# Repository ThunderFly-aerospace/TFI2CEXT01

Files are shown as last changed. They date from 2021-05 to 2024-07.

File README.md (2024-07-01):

# TFI2CEXT01A - I²C bus extender

I²C bus extension module. This module allows an extension of the usable total length of the I2C bus on the UAV. Most I2C bus instances benefit from having TFI2CEXT positioned midway between master and slave, where its signal amplification is most effective in both directions.

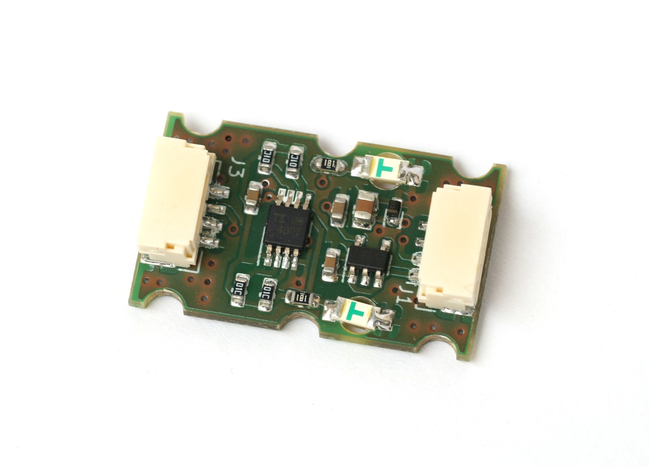
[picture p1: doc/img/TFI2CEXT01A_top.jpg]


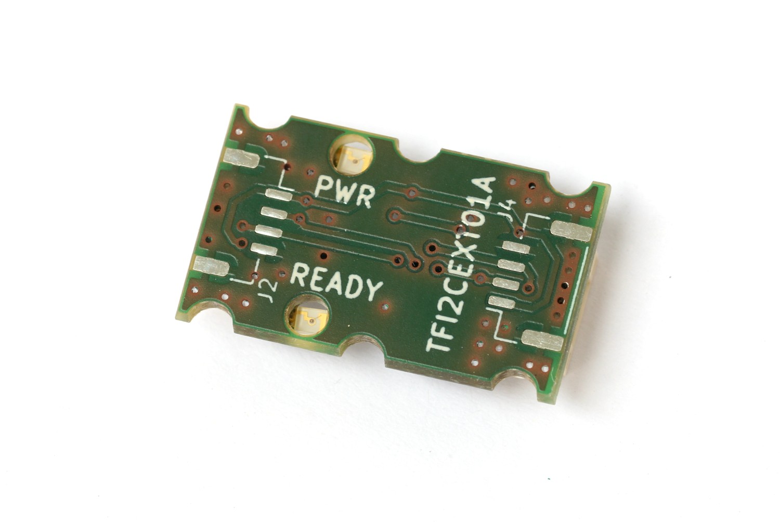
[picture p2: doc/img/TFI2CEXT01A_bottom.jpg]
Bottom view on I2C bus extender


In practice, I2C devices vary in driving capability, and I2C signals are often affected by capacitive load or unwanted signal coupling. TFI2CEXT can effectively isolate bus segments, ensuring devices only see the segment's wiring load up to the TFI2CEXT. Thus, placing TFI2CEXT closer to the "problematic" I²C device is optimal.

## Where to get it?

ThunderFly TFI2CEXT01A counter is commercially available from [ThunderFly s.r.o.](https://www.thunderfly.cz/), write an email to info@thunderfly.cz. Or shop it on [Tindie.](https://www.tindie.com/products/thunderfly/tfi2cext01-pixawk-i2c-bus-extender/)

## Parameters

| Parameter | Value | Description |
|---|---|---|
| Data rate | Up to 400 kHz | Limited by used [TCA4307 IC](https://www.ti.com/product/TCA4307) |
| I2C Connector | 2x 4-pin JST-GH | Connected in parallel |
| Operating and storage temperature | -20 - +40°C | Limited by case material |
| Operational input voltage | 3.6 - 5.4V |  |
| Mass | ~2 g | PCB |
| Dimensions | 15x25x6(10.5) | One-sided connectors (With connector on both sides) |
| Weather resistance | IP00 |  |

## Features

  * Input Power status LED indicator
  * Optionally possible to solder pass-through I²C connectors to allow a daisy chain of different sensors
  * Ability to isolate I2C bus segments by disconnecting frozen devices
  * Capability to handle differently the Master and a slave bus sides
  * The extender can perform a device reset in case it seems frozen or unresponsive.
  * READY signal indication of the correct connection of both I2C bus sides.

The two I²C Pixhawk connectors on the bottom and top are connected directly. This feature allows easy nesting with other I²C devices onto existing functional bus cabling.

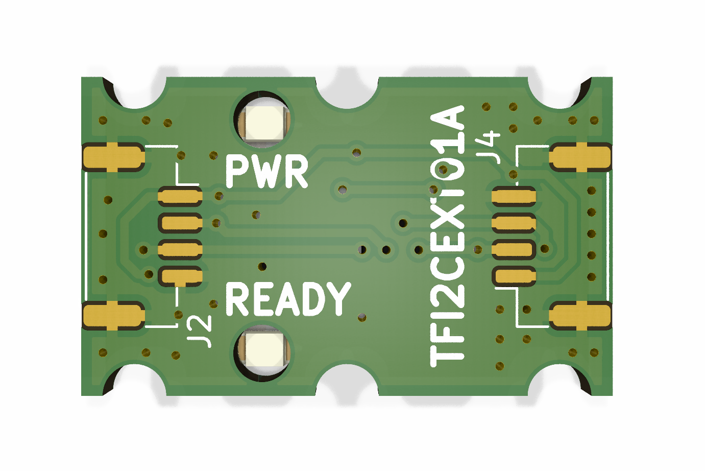
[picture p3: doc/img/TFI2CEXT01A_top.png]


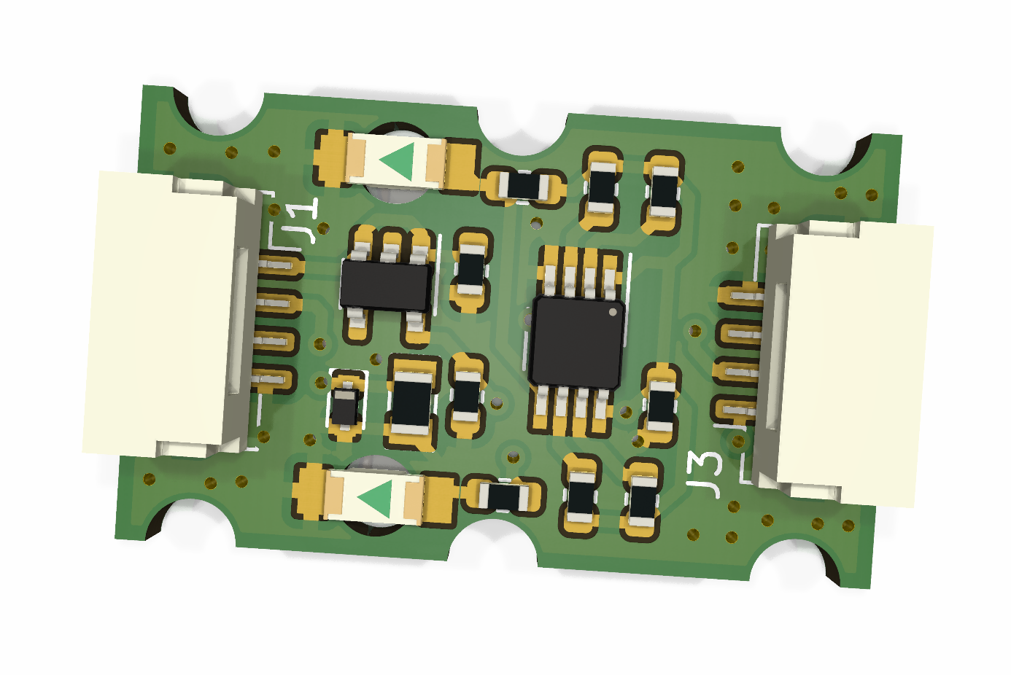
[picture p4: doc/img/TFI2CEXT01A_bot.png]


### Device Reset

The TCA4307 has a stuck bus recovery feature. It disconnects the slave side if SDAOUT or SCLOUT is low for about 40 ms, then generates up to 16 pulses on SCLOUT to reset the bus. The slave side reconnects only after the issue is resolved.

### PCB dimensions

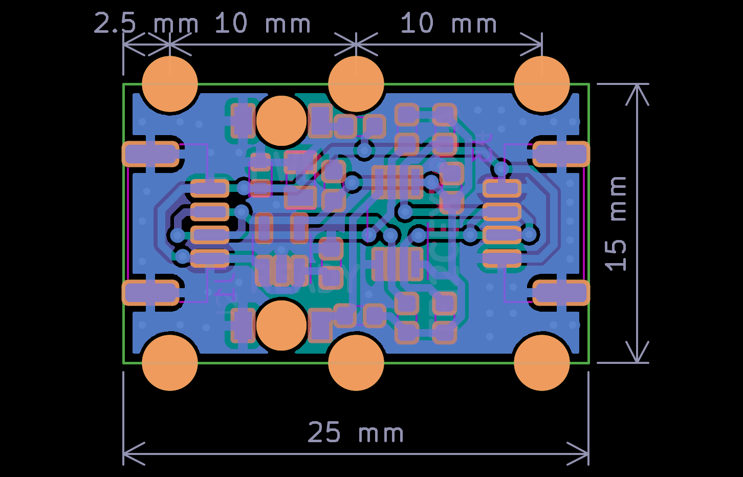
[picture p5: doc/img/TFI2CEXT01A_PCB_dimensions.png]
PCB dimensions


The PCB is designed to be mounted in the slit and fixed by screws on the sides. The supposed screw diameter is metric 3mm e.g. DIN 912 M3 Hexagon socket Head Cap Screws.

## Documentation

The additional documentation is available on the [ThunderFly docs website](https://docs.thunderfly.cz/avionics/TFI2CEXT/). 

### Connection 

Due to the device reset capability of TFI2CEXT01 special attention should be dedicated to the proper connection of the module to the UAV. The connector closer to the LEDS should be connected to the Master (e.g. autopilot). The opposite connector at the far side from LEDs should be connected to I²C slaves, e.g. sensors.

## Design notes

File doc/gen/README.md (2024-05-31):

# PCB

Board size: 25.0x15.0 mm (0.98x0.59 inches)

- This is the size of the rectangle that contains the board
- Thickness: 1.6 mm (63 mils)
- Material: FR4
- Finish: None
- Layers: 2
- Copper thickness: 35 µm

Solder mask: TOP / BOTTOM

- Color: Green

Silk screen: TOP / BOTTOM

- Color: White

Stackup:

| Name | Type | Color | Thickness | Material | Epsilon_r | Loss tangent |
|---|---|---|---|---|---|---|
| F.SilkS | Top Silk Screen | | | | | |
| F.Paste | Top Solder Paste | | | | | |
| F.Mask | Top Solder Mask | Green | 10 | | | |
| F.Cu | copper | | 35 | | | |
| dielectric 1 | core | | 1510 | FR4 | 4.5 | 0.020 |
| B.Cu | copper | | 35 | | | |
| B.Mask | Bottom Solder Mask | Green | 10 | | | |
| B.Paste | Bottom Solder Paste  | | | | | |
| B.SilkS | Bottom Silk Screen | | | | | |

# Important sizes

Clearance: 0.2 mm (8 mils)

Track width: 0.25 mm (10 mils)

- By design rules: 0.2 mm (8 mils)

Drill: 0.5 mm (20 mils)

- Vias: 0.5 mm (20 mils) [Design: 0.4 mm (16 mils)]
- Pads: 3.0 mm (118 mils)
- The above values are real drill sizes, they add 0.1 mm (4 mils) to plated holes (PTH)

Via: 0.8/0.4 mm (31/16 mils)

- By design rules: 0.4/0.3 mm (16/12 mils)
- Micro via: yes [0.2/0.1 mm (8/4 mils)]
- Buried/blind via: yes
- Total: 47 (thru: 47 buried/blind: 0 micro: 0)

Outer Annular Ring: 0.15 mm (6 mils)

- By design rules: N/A mm (N/A mils)

Eurocircuits class: 4B
- Using min drill 0.5 mm for an OAR of 0.15 mm

# General stats

Components count: (SMD/THT)

- Top: 2/6 (SMD + THT)
- Bottom: 17/0 (SMD)

Defined tracks:

Used tracks:

- 0.25 mm (10 mils) (2) defined: no
- 0.3 mm (12 mils) (1) defined: no
- 0.4 mm (16 mils) (144) defined: no

Defined vias:

Used vias:

- 0.8/0.4 mm (31/16 mils) (Count: 47, Aspect: 2.0 A) defined: no

Holes (excluding vias):

- 3.0 mm (118 mils) (6)

Oval holes:

Drill tools (including vias and computing adjusts and rounding):

- 0.5 mm (20 mils) (47)
- 3.0 mm (118 mils) (6)

Solder paste stats:

Using a paste with 87.75 % alloy, that has an specific gravity for the alloy of 7.4 g/cm³
and 1.0 g/cm³ for the flux. This paste has an specific gravity of  4.15 g/cm³.

The stencil thickness is  0.12 mm.

| Side | Pads with paste | Area [mm²] | Paste [g] |
|---|---|---|---|
| Top | 12 | 18.56 | 0.09 |
| Bottom | 51 | 51.67 | 0.26 |
| Total  | 63 | 70.22 | 0.35 |

Note: this is just an approximation to the theoretical value. Margins of the solder mask and waste aren't computed.

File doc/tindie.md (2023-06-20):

## What is TFI2CEXT? 

TFI2CEXT01 is a device or module, that contains an I2C bus buffer, the electronic component that enhances the signal on an I2C bus. The buffer creates a signal that is less prone to interference or large capacity of wires which is a common issue among usual I2C devices. Thanks to this feature, it is possible, for example, to elongate the I2C bus or connect more devices to one I2C bus. 

TFI2CEXT is designed directly for use in drone avionics. For this purpose, for example, it features a JST-GH connector with a pinout corresponding to the Pixhawk standard on both input and output.

## What makes TFI2CEXT special? 

ThunderFly I2CEXT device is unique in that it can be connected directly (without major changes) to the infrastructure of drones based on the Pixhawk standard.

## What are TFI2CEXT main features?
  
  * Input Power status LED indicator
  * Optional possibility of soldering pass-through I²C connectors to allow a daisy chain topology
  * Ability to isolate I2C bus segments by disconnecting frozen devices (Frozen devices are automatically attempted to reset)
  * Capability to handle a master and a slave bus sides differently
  * The extender is capable to perform a device reset if it seems to be frozen
  * READY signal indication of the correct connection of both I2C bus sides

The main reason for developing TFI2CEXT was that we repeatedly experienced a state when an I2C bus on drones was not reliable enough to be used safely. After developing our device the situation improved significantly and the problems with communication on the I2C bus disappeared.

## How TFI2CEXT could be used?

Using the I2C extender is very simple - it works by plugging into the bus, preferably into the middle of the bus wire's longest section. The PCB can be fitted with JST-GH connectors from both sides, the connectors are connected in parallel. This allows the TFI2CEXT PCB to act as a small I2C hub. There are 2 input connectors (before the I2C buffer) and 2 connectors enhanced by the I2C buffer.

The module contains 2 LED diodes. One indicates the presence of a power supply and should be lit all the time the power supply is present. The second - READY LED - lights up only if both sides of the bus are connected, the module is functional and ready to enhance the I2C bus transmissions.

### Compatibility

The bus buffer does not need any software configuration. Thanks to this, it can be used with any Pixhawk autopilot compatible firmware like [PX4](https://px4.io/) or [Ardupilot](https://ardupilot.org/) additionally the usage is not limited to UAVs only.

## What package includes

- TFI2CEXT01A
- Two spare JST-GH PCB connectors (only two connectors are soldered on PCB by default)

## Accessories

### I2C cables
I2C cables for connecting to the autopilot are not included in the package. You will need to purchase the cables separately from our [tindie catalog](https://www.tindie.com/stores/thunderfly/). We offer high-quality cables that are compatible with the [Pixhawk standard](https://raw.githubusercontent.com/pixhawk/Pixhawk-Standards/master/DS-009%20Pixhawk%20Connector%20Standard.pdf) and with a [ThunderFly color](https://docs.px4.io/main/en/assembly/cable_wiring.html#i2c-cables) scheme for easy signal identification. Our cables are specifically designed with improved resistance to electromagnetic interference and made with silicone insulation that makes them highly flexible.

  * Length 15 cm - [TFCAB15I2C01](https://www.tindie.com/products/thunderfly/tfcabxxi2c01-i2c-cable-for-pixhawk-drones/)
  * Length 30 cm - [TFCAB30I2C01](https://www.tindie.com/products/thunderfly/tfcabxxi2c01-i2c-cable-for-pixhawk-drones/)
  * Length 45 cm - [TFCAB45I2C01](https://www.tindie.com/products/thunderfly/tfcabxxi2c01-i2c-cable-for-pixhawk-drones/)

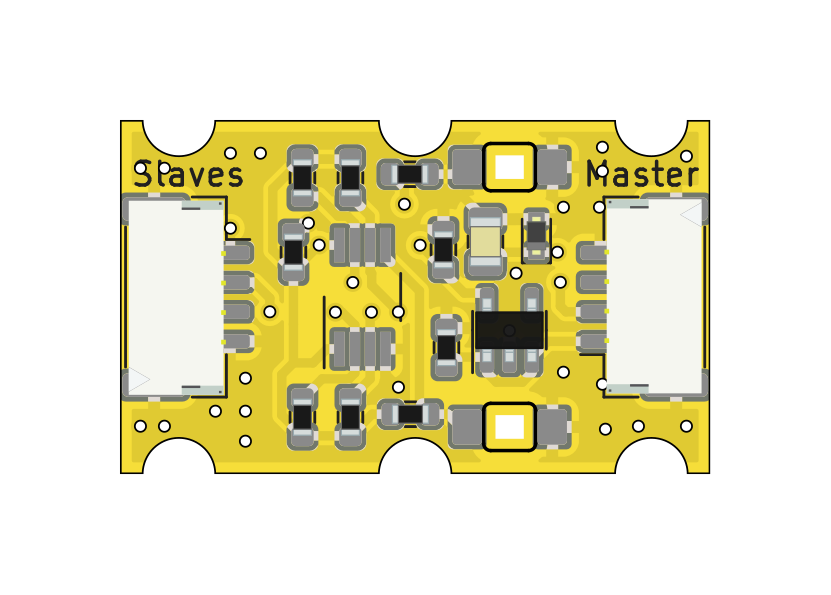
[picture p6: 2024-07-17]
doc/gen/img/TFI2CEXT01-bottom.png

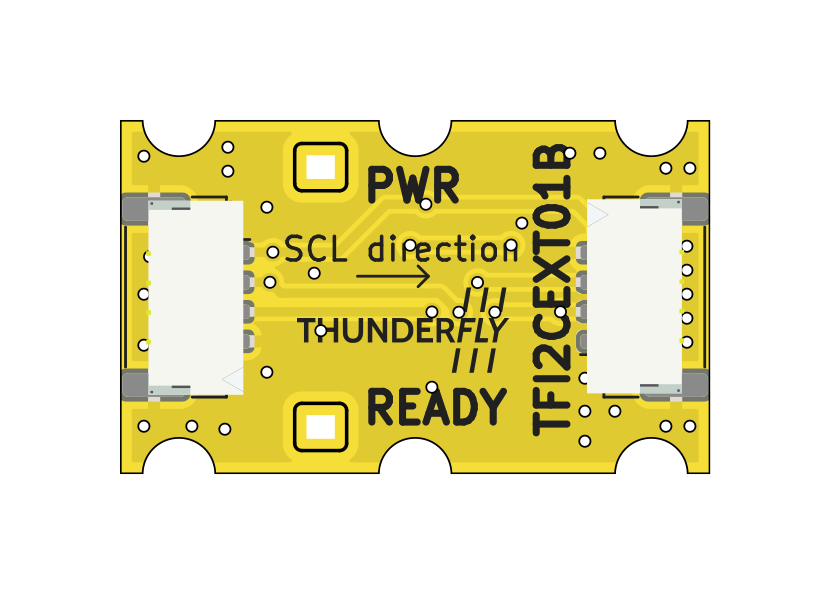
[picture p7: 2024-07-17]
doc/gen/img/TFI2CEXT01-top.png

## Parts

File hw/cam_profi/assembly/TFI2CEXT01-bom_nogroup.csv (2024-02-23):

Component | Description | Part | References | Value | Footprint | Quantity Per PCB | Datasheet | ust_id
1 | Unpolarized capacitor | C | C2C4 | 100nF | R_0603_1608Metric | 2 | ~ | 5c70984812875079b91f8bf2
2 | Unpolarized capacitor | C | C3 | 1uF | R_0603_1608Metric | 1 | ~ | 5c70984812875079b91f8bc2
3 | Unpolarized capacitor | C | C1 | 10uF | C_0805_2012Metric | 1 | ~ | 5c70984812875079b91f8bbd
4 |  | D_ZENER | D2 | BZX585-B5V6.115 | D_SOD-523 | 1 |  | 60879d38128750769ee58e48
5 | Light emitting diode | LED | D1 | LED GREEN | LED_1206_mill | 1 | ~ | 5c70984412875079b91f8895
6 | Light emitting diode | LED | D3 | LED RED | LED_1206_mill | 1 | ~ | 5c70984412875079b91f8896
7 | 1x05 2.54 mm pitch header | SM04B-GHS-TB | J1J2J3J4 | SM04B-GHS-TB | JST_GH_SM04B-GHS-TB_1x04-1MP_P1.25mm_Horizontal | 4 |  | 5c86273d1287500b4e0280be
8 |  | HOLE | M1M2M3M4M5M6 | HOLE | dira_3mm | 6
9 | Resistor | R | R1 | 130R | R_0603_1608Metric | 1 | ~ | 5cd08b17128750448e4542b1
10 | Resistor | R | R4 | 287R | R_0603_1608Metric | 1 | ~ | 651a975c462c6d9e7205504d
11 | Resistor | R | R2R3R5R6 | 10k | R_0603_1608Metric | 4 | ~ | 5c70984512875079b91f8962
12 | 300mA Low-dropout Voltage Regulator, Vout 3.3V, Vin up to 5.5V, SOT-23 | MIC5504-3.3YM5 | U1 | MIC5504-3.3YM5 | SOT-23-5 | 1 | http://ww1.microchip.com/downloads/en/DeviceDoc/MIC550X.pdf | 5c7255e81287500b4e112ea2
13 |  | TCA4307 | U2 | TCA4307 | VSSOP-8_3.0x3.0mm_P0.65mm | 1 | https://www.ti.com/lit/ds/symlink/tca4307.pdf?ts=1617607418171 | 6087a3f3128750769ee58f03

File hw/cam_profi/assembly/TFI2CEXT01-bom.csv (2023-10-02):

Row | Description | Part | References | Value | Footprint | Quantity Per PCB | Status | Datasheet | UST_id
1 | Unpolarized capacitor | C | C2 C4 | 100nF | R_0603_1608Metric | 2 |  |  | 5c70984812875079b91f8bf2
2 | Unpolarized capacitor | C | C3 | 1uF | R_0603_1608Metric | 1 |  |  | 5c70984812875079b91f8bc2
3 | Unpolarized capacitor | C | C1 | 10uF | C_0805_2012Metric | 1 |  |  | 5c70984812875079b91f8bbd
4 |  | D_ZENER | D2 | BZX585-B5V6.115 | D_SOD-523 | 1 |  |  | 60879d38128750769ee58e48
5 | Light emitting diode | LED | D1 | LED GREEN | LED_1206_mill | 1 |  |  | 5c70984412875079b91f8895
6 | Light emitting diode | LED | D3 | LED RED | LED_1206_mill | 1 |  |  | 5c70984412875079b91f8896
7 | 1x05 2.54 mm pitch header | SM04B-GHS-TB | J1 J2 J3 J4 | SM04B-GHS-TB | JST_GH_SM04B-GHS-TB_1x04-1MP_P1.25mm_Horizontal | 4 |  |  | 5c86273d1287500b4e0280be
8 |  | HOLE | M1 M2 M3 M4 M5 M6 | HOLE | dira_3mm | 6
9 | Resistor | R | R1 | 130R | R_0603_1608Metric | 1 |  |  | 5cd08b17128750448e4542b1
10 | Resistor | R | R4 | 287R | R_0603_1608Metric | 1 |  |  | 651a975c462c6d9e7205504d
11 | Resistor | R | R2 R3 R5 R6 | 10k | R_0603_1608Metric | 4 |  |  | 5c70984512875079b91f8962
12 | 300mA Low-dropout Voltage Regulator, Vout 3.3V, Vin up to 5.5V, SOT-23 | MIC5504-3.3YM5 | U1 | MIC5504-3.3YM5 | SOT-23-5 | 1 |  | http://ww1.microchip.com/downloads/en/DeviceDoc/MIC550X.pdf | 5c7255e81287500b4e112ea2
13 |  | TCA4307 | U2 | TCA4307 | VSSOP-8_3.0x3.0mm_P0.65mm | 1 |  | https://www.ti.com/lit/ds/symlink/tca4307.pdf?ts=1617607418171 | 6087a3f3128750769ee58f03
Project info:
Schematic: | TFI2CEXT01
Variant: | default
Revision:
Date: | 2021-04-05
KiCad Version: | 7.0.7-7.0.7~ubuntu23.04.1
Statistics:
Component Groups: | 13
Component Count: | 25
Fitted Components: | 25
Number of PCBs: | 1
Total Components: | 25

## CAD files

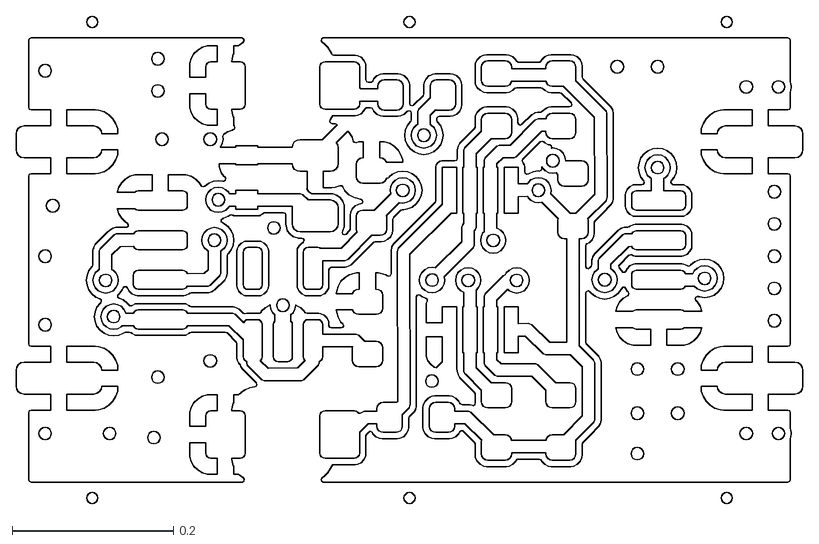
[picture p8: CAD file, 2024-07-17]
doc/gen/dxf/TFI2CEXT01-B_Cu.dxf
0.976 x 0.604

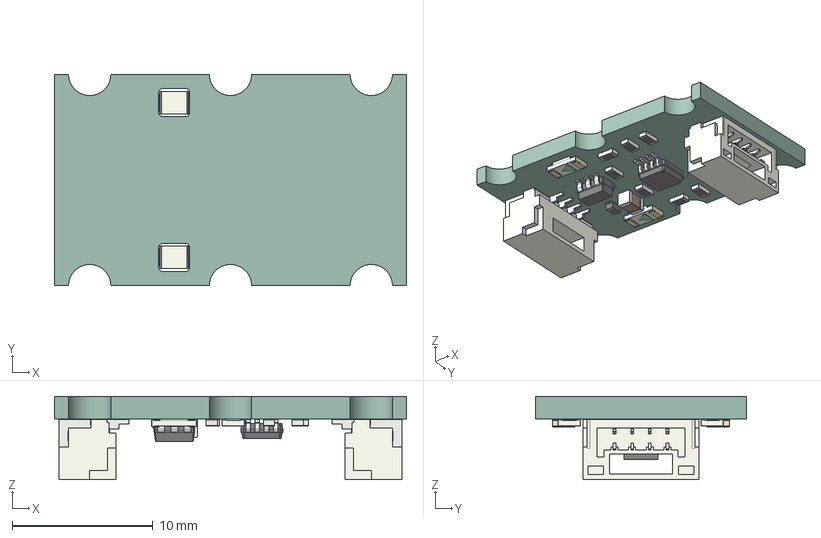
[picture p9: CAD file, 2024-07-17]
doc/gen/TFI2CEXT01.step
25.0 x 15.0 x 5.89 mm
R_0603_1608Metric x 9
VSSOP_8_30x30mm_P065mm
LED_1206_3216Metric x 2
D_SOD_523
JST_SM04B_GHS_TB x 2
SOT_23_5
C_0805_2012Metric
kibot_1q7gwn4h_PCB

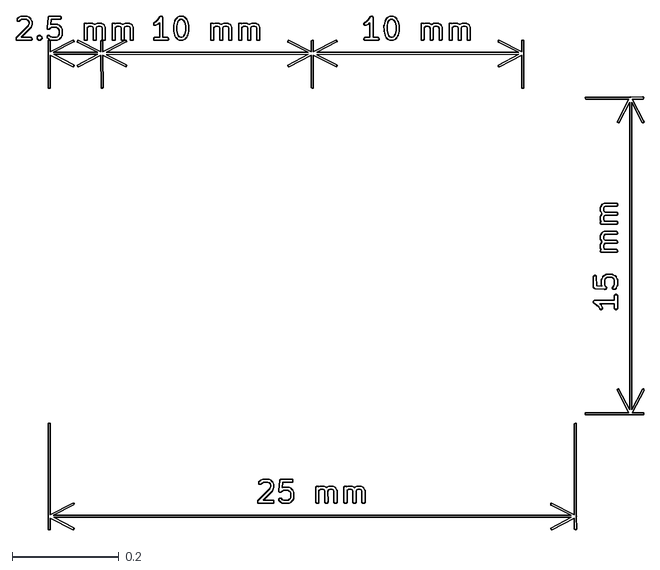
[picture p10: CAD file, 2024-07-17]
doc/gen/dxf/TFI2CEXT01-User_Drawings.dxf
1.17 x 0.961

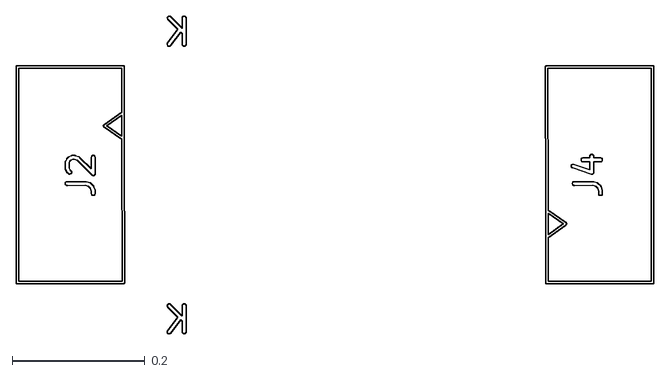
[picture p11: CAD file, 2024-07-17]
doc/gen/dxf/TFI2CEXT01-F_Fab.dxf
0.961 x 0.478

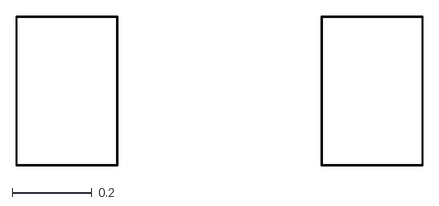
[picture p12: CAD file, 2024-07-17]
doc/gen/dxf/TFI2CEXT01-F_Courtyard.dxf
1.02 x 0.374

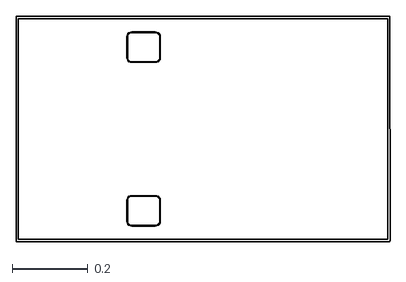
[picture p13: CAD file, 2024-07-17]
doc/gen/dxf/TFI2CEXT01-Edge_Cuts.dxf
0.99 x 0.596

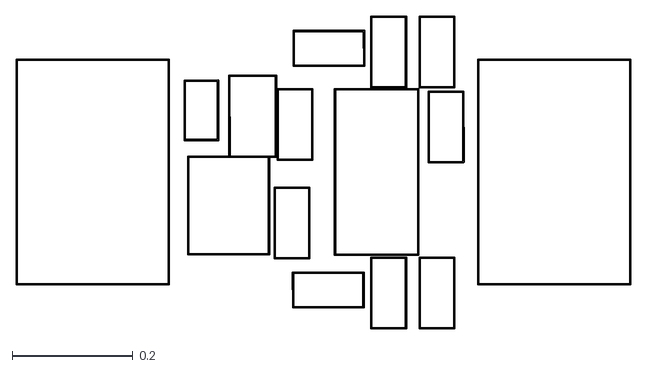
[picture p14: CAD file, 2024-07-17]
doc/gen/dxf/TFI2CEXT01-B_Courtyard.dxf
1.02 x 0.518

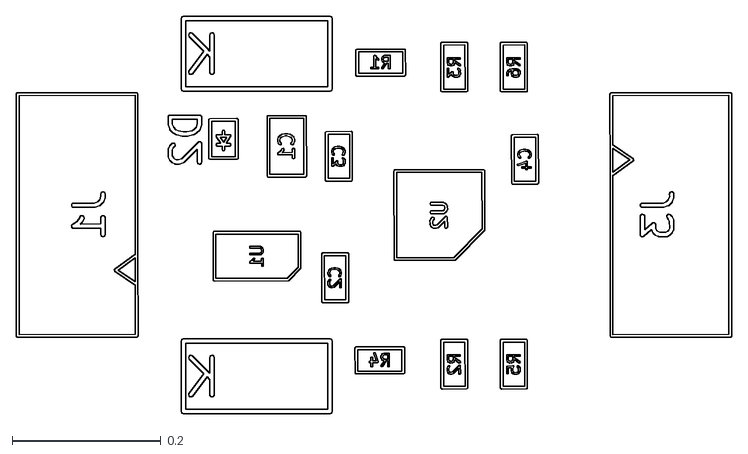
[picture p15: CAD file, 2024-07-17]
doc/gen/dxf/TFI2CEXT01-B_Fab.dxf
0.961 x 0.533

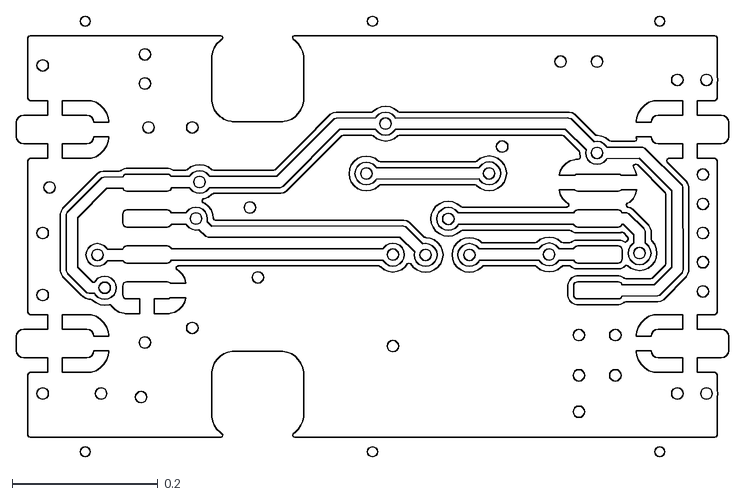
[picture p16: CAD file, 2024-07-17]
doc/gen/dxf/TFI2CEXT01-F_Cu.dxf
0.976 x 0.604

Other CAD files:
doc/gen/dxf/TFI2CEXT01-Margin.dxf
doc/gen/dxf/TFI2CEXT01-B_Mask.dxf
doc/gen/dxf/TFI2CEXT01-B_Paste.dxf
doc/gen/dxf/TFI2CEXT01-B_Silkscreen.dxf
doc/gen/dxf/TFI2CEXT01-F_Mask.dxf
doc/gen/dxf/TFI2CEXT01-F_Paste.dxf
doc/gen/dxf/TFI2CEXT01-F_Silkscreen.dxf

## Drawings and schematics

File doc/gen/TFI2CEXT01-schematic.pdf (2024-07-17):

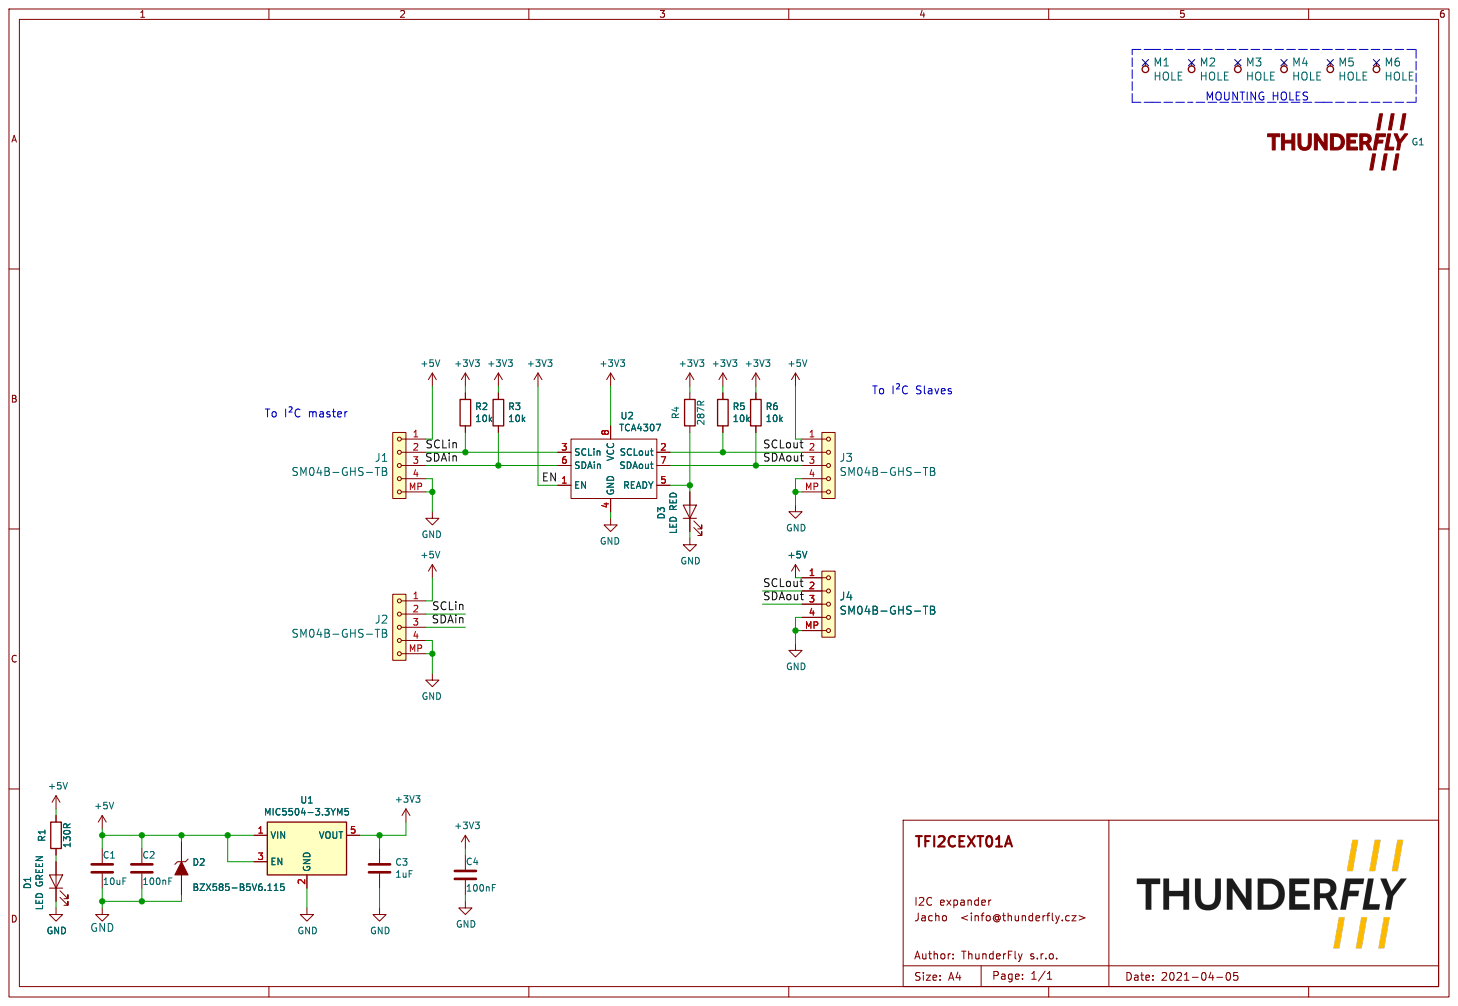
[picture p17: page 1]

4 READY 5 SDAin 6 SDAout VCC 7

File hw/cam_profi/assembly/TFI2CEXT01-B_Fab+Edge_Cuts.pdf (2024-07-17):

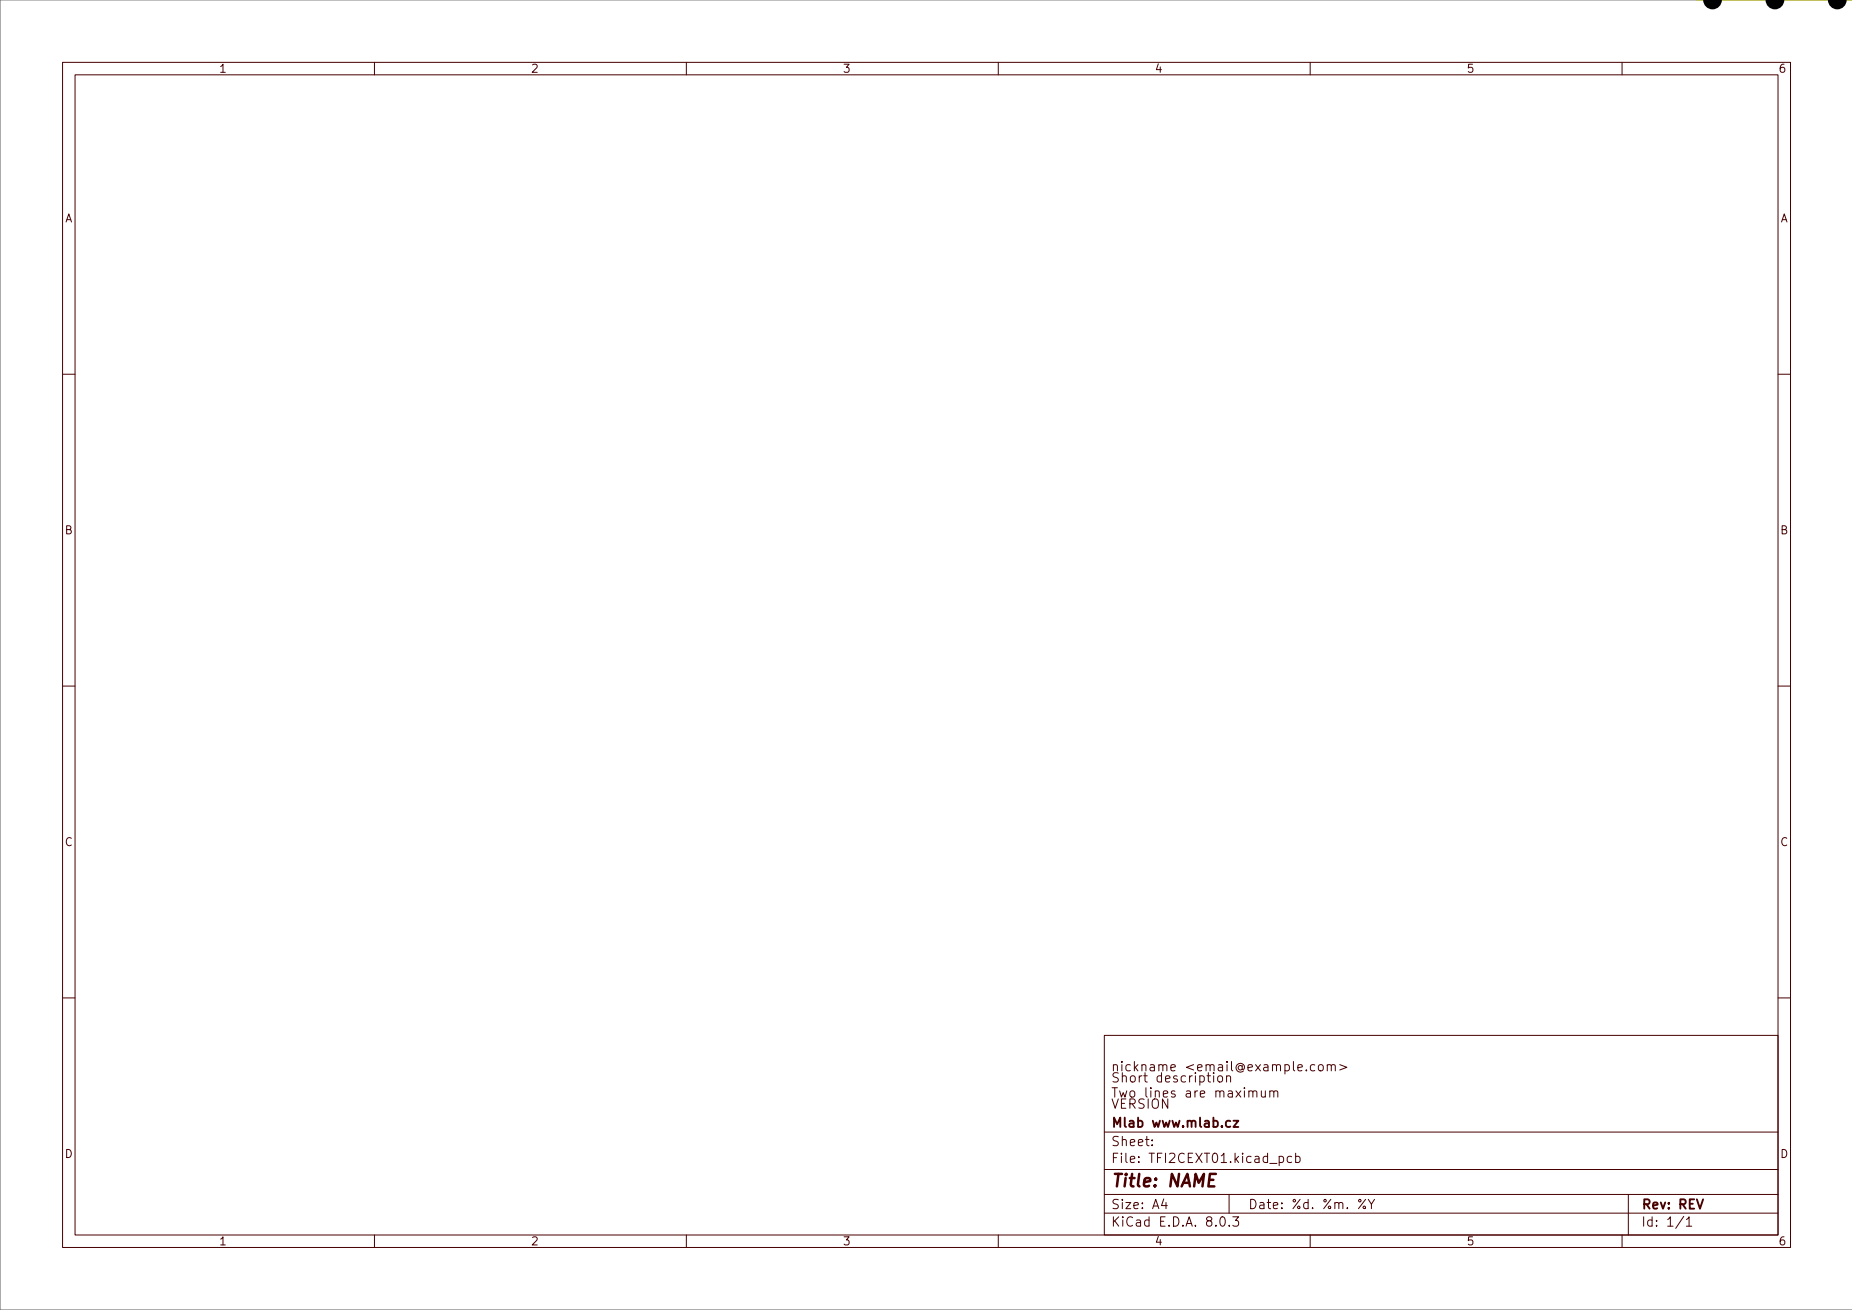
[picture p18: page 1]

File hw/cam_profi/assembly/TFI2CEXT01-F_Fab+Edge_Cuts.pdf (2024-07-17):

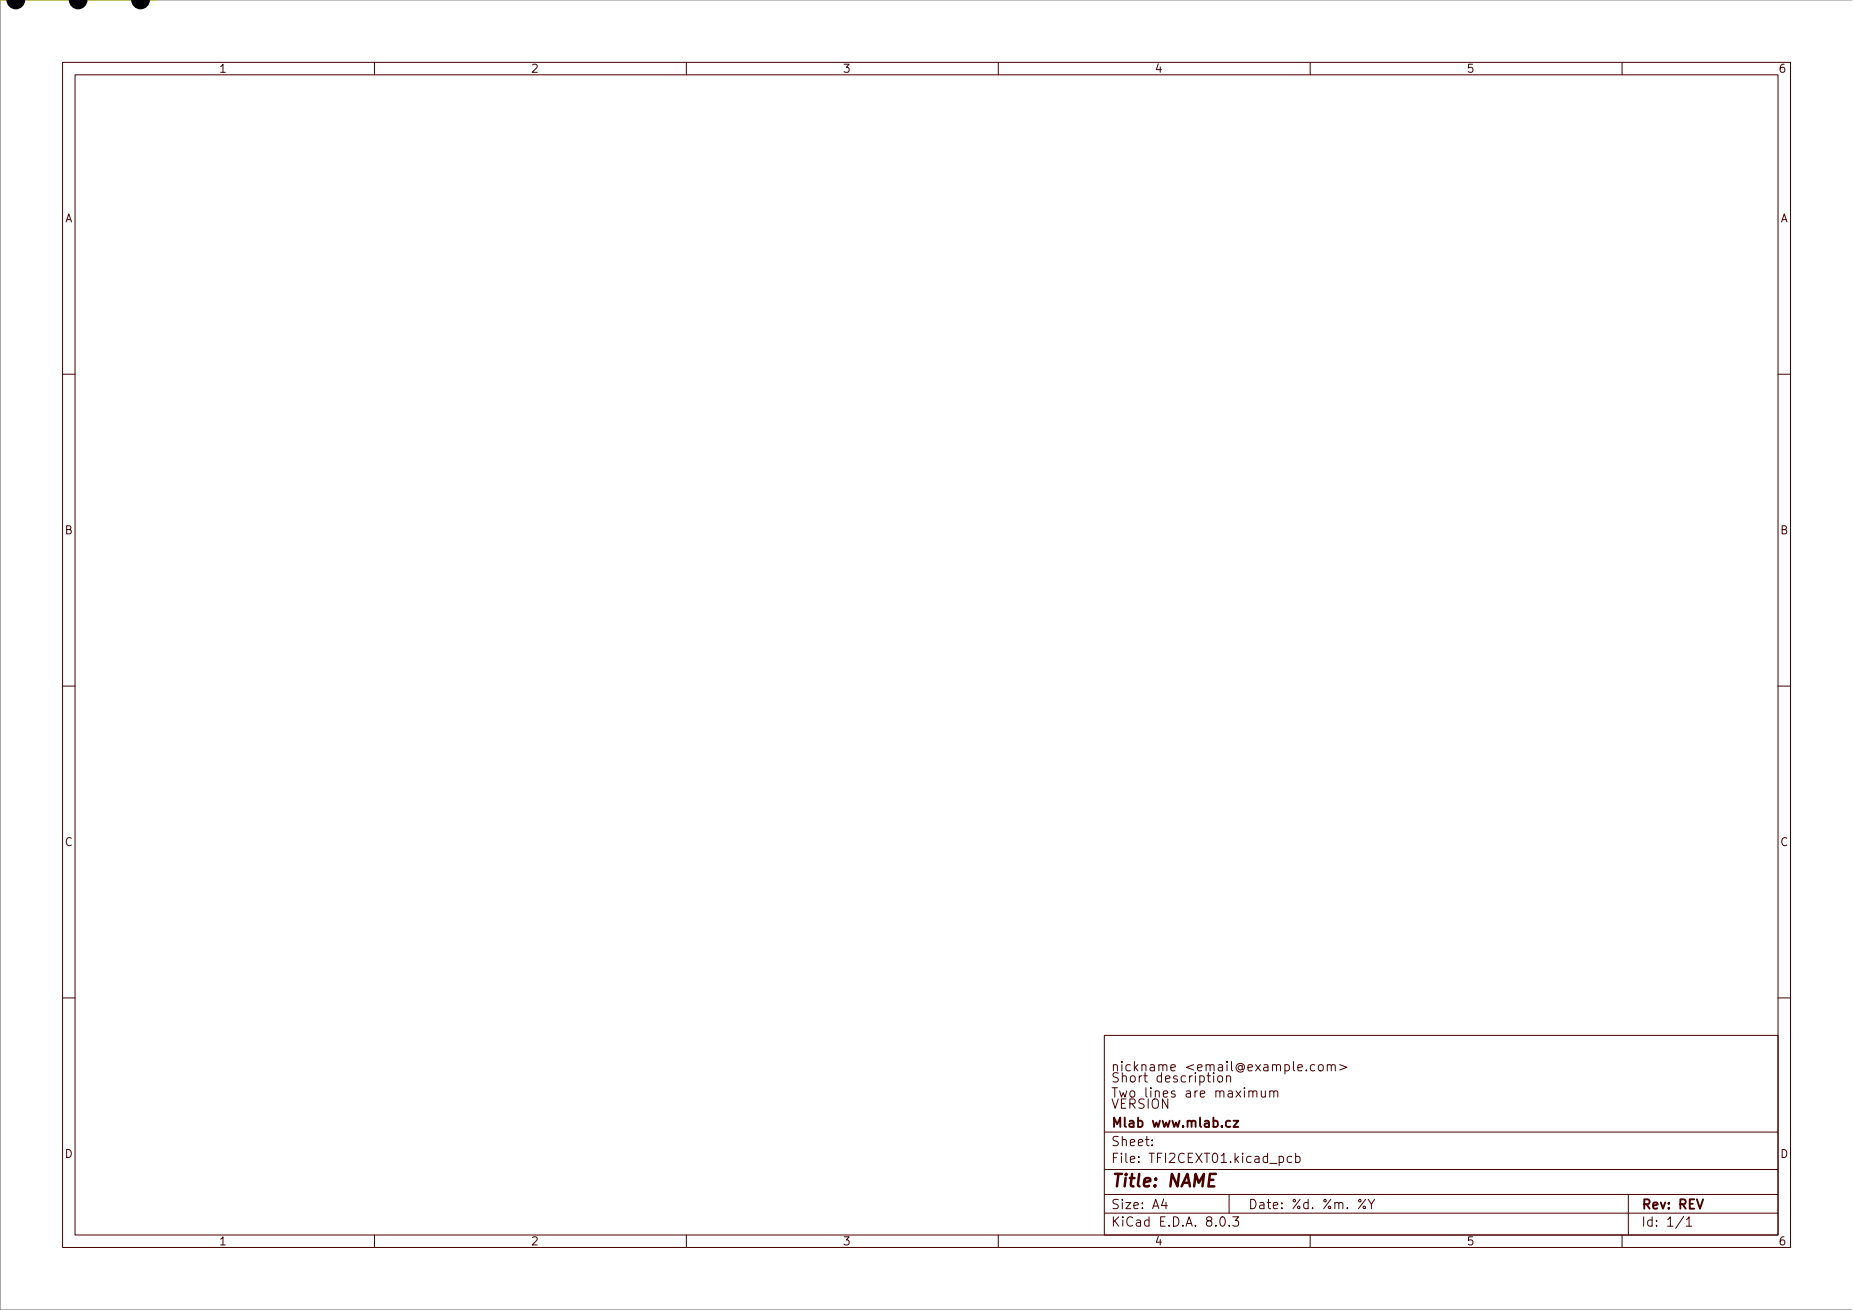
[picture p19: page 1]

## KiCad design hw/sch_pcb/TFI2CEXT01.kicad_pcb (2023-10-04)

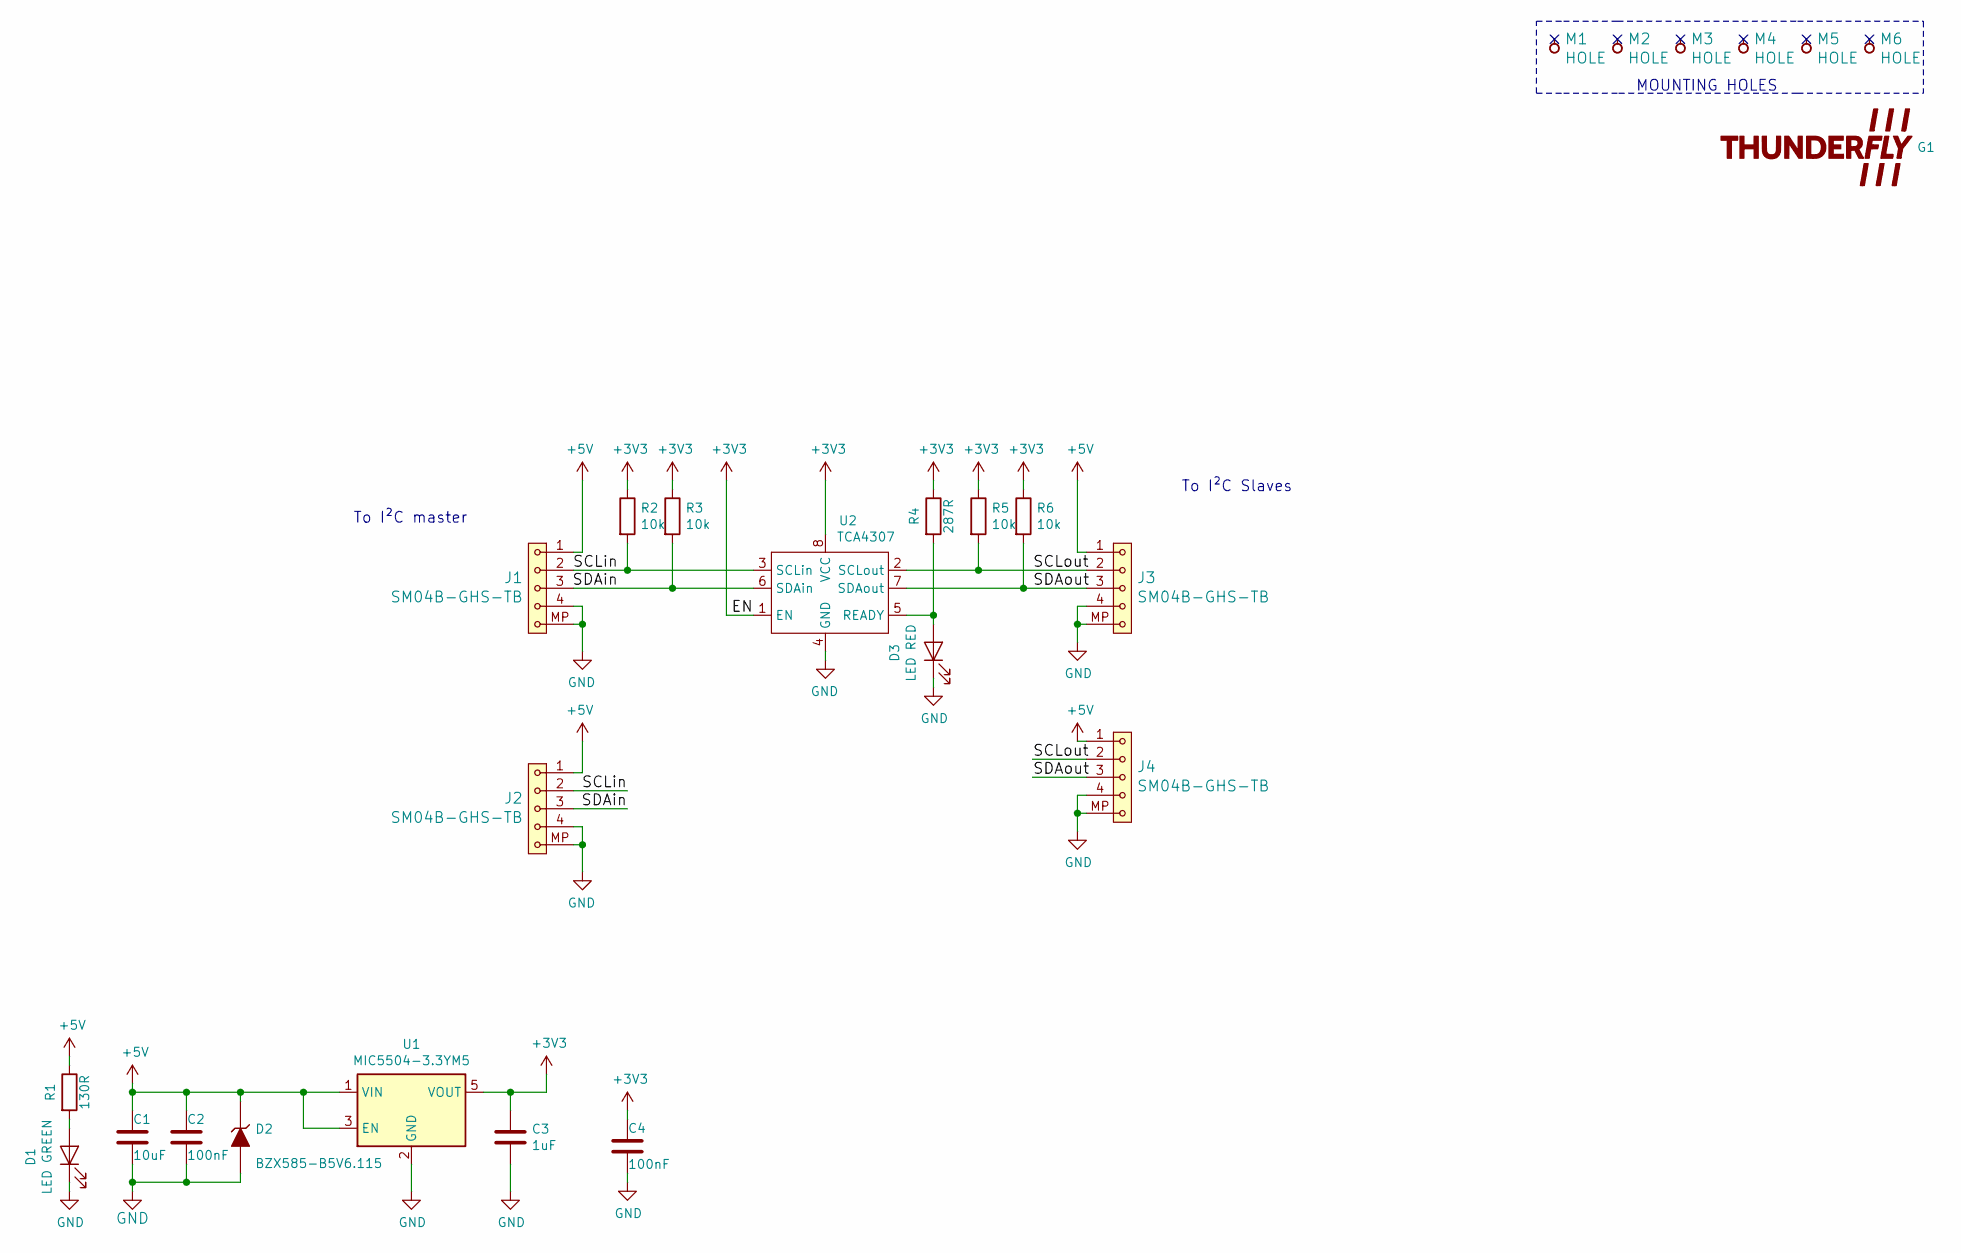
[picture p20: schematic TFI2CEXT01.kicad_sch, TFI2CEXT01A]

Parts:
C1: 10uF; C_0805_2012Metric
C2, C4: 100nF; R_0603_1608Metric
C3: 1uF; R_0603_1608Metric
D1: LED GREEN; LED_1206_mill
D2: BZX585-B5V6.115; D_SOD-523
D3: LED RED; LED_1206_mill
G1: LOGO; TF 10x4,7
J1, J2, J3, J4: SM04B-GHS-TB; JST_GH_SM04B-GHS-TB_1x04-1MP_P1.25mm_Horizontal
M1, M2, M3, M4, M5, M6: HOLE; dira_3mm
R1: 130R; R_0603_1608Metric
R2, R3, R5, R6: 10k; R_0603_1608Metric
R4: 287R; R_0603_1608Metric
U1: MIC5504-3.3YM5; SOT-23-5
U2: TCA4307; VSSOP-8_3.0x3.0mm_P0.65mm

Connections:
+3V3: C3.1, C4.1, R2.1, R3.1, R4.1, R5.1, R6.1, U1.5 (VOUT), U2.1 (EN), U2.8 (VCC)
+5V: C1.1, C2.1, D2.1 (K), J1.1, J2.1, J3.1, J4.1, R1.1, U1.1 (VIN), U1.3 (EN)
/SCLin: J1.2, J2.2, R2.2, U2.3 (SCLin)
/SCLout: J3.2, J4.2, R5.2, U2.2 (SCLout)
/SDAin: J1.3, J2.3, R3.2, U2.6 (SDAin)
/SDAout: J3.3, J4.3, R6.2, U2.7 (SDAout)
GND: C1.2, C2.2, C3.2, C4.2, D1.1 (K), D2.2 (A), D3.1 (K), J1.4, J1.MP, J2.4, J2.MP, J3.4, J3.MP, J4.4, J4.MP, U1.2 (GND), U2.4 (GND)
unnamed: D1.2 (A), R1.2
unnamed: D3.2 (A), R4.2, U2.5 (READY)

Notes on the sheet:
To I²C Slaves
To I²C master
MOUNTING HOLES

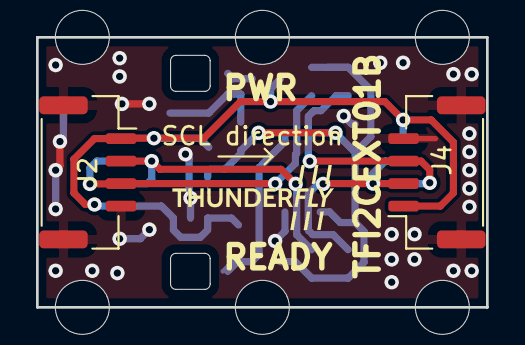
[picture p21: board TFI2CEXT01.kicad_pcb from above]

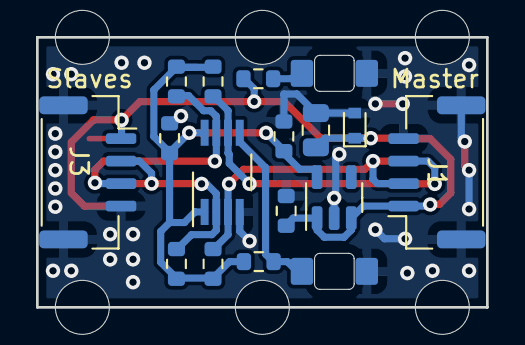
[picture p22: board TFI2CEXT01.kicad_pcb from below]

Board: 2 copper layers, 25.0 x 15.0 mm, 26 parts (17 on the bottom side), 9 nets.

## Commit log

2021-05-25 First schematics
    [TFI2CEXT01A.kicad_pcb, TFI2CEXT01A.kicad_sch]
2021-05-25 Update title block.
    [TFI2CEXT01A.kicad_sch]
2021-05-25 Add secondary input connector #2.
    [TFI2CEXT01A.kicad_sch]
2021-05-25 The first layout
    [TFI2CEXT01A.kicad_pcb, TFI2CEXT01A.kicad_sch]
2021-05-25 Edit PCB
    [TFI2CEXT01A.kicad_pcb, TFI2CEXT01A.kicad_sch]
2021-05-25 Layout improvement.
    [TFI2CEXT01A.kicad_pcb]
2021-05-25 Generating production data
    [TFI2CEXT01A-B_Cu.gbr, TFI2CEXT01A-B_Mask.gbr, TFI2CEXT01A-B_Silkscreen.gbr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]
2021-05-25 Finishing the design
    [TFI2CEXT01A.kicad_pcb]
2021-05-25 Update documentation.
    [TFI2CEXT01A-User_Drawings.gbr]
2021-05-25 Crop black boarder from the images.
2021-06-06 Improved Slave and Master side marking. #6.
    [TFI2CEXT01A.kicad_pcb, TFI2CEXT01A.kicad_sch]
2023-05-27 rename source files
    [TFI2CEXT01.kicad_pcb, TFI2CEXT01.kicad_sch, TFI2CEXT01A.csv]
2023-09-27 Upravy pred vyrobou 01B
    [TFI2CEXT01.kicad_pcb, TFI2CEXT01.kicad_sch]
2023-09-27 Edit kicad_outputs.yml
2023-09-27 Update actions products
    [TFI2CEXT01-B_Courtyard.dxf, TFI2CEXT01-B_Cu.dxf, TFI2CEXT01-B_Fab.dxf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]
2023-09-27 Add pasta layers
    [TFI2CEXT01.kicad_pcb]
2023-10-02 Edit UST_ID
    [TFI2CEXT01.kicad_sch]
2023-10-04 Edit B.Fab
    [TFI2CEXT01.kicad_pcb]
